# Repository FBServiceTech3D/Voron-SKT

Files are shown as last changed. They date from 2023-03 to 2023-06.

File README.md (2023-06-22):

# Voron SKT Toolhead
Mod for Voron with umbilical 
<br/>
<br/>
SKT stands for "Skinny Tool" :)<br/>
Some things are inspired by EVA 2, thanks guys.<br/>
This toolhead is designed to be as light as possible with a "TAP" like probe. It will not be compatible with all extruders and all hotends or even with all types of toolboards due to its design and specificity.<br/>
STK toolhead allow the installation of SHT42/EBB42 toolboards only.><br/>
If you want to run fast, just try it.<br/><br/>
<B>Whit this mod you will able to use all the build plate on X axis, but you will lose about 8mm on Y axis</B><br/>
 
<br/>

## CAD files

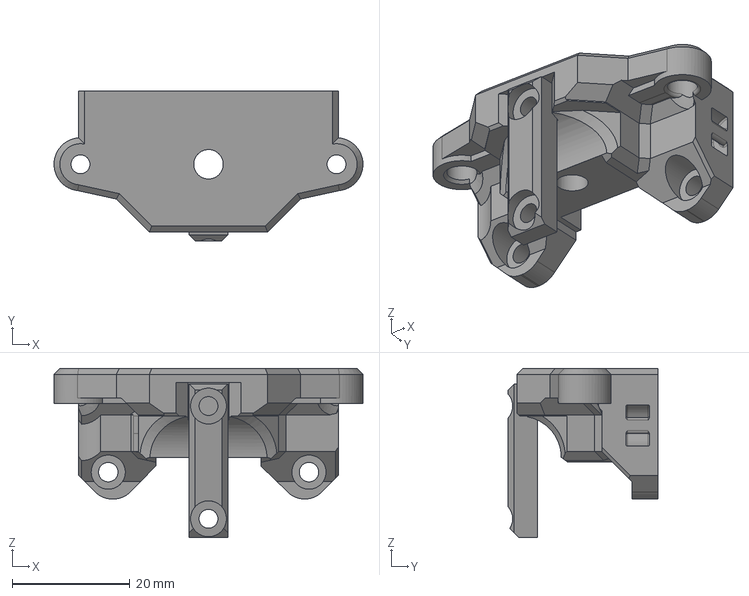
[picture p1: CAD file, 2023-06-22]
Stuff/CAD/Sherpa Mini - Stiffer v2.step
52.5 x 25.4 x 28.8 mm

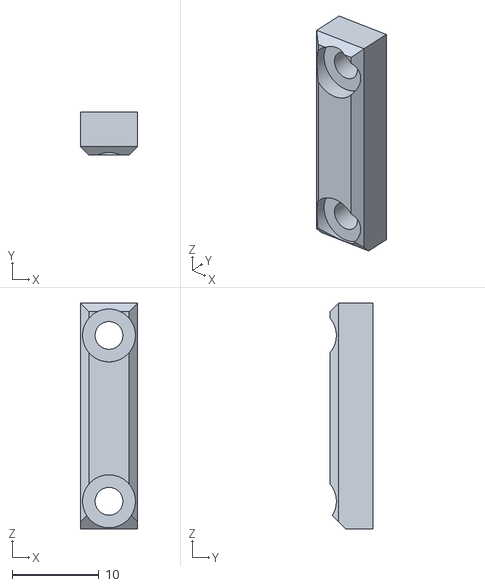
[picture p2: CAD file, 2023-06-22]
Stuff/STL/1.3 - Tap/Extruders/Sherpa micro stiffer/Barra irrigidimento.stl
6.60 x 5.00 x 26.1

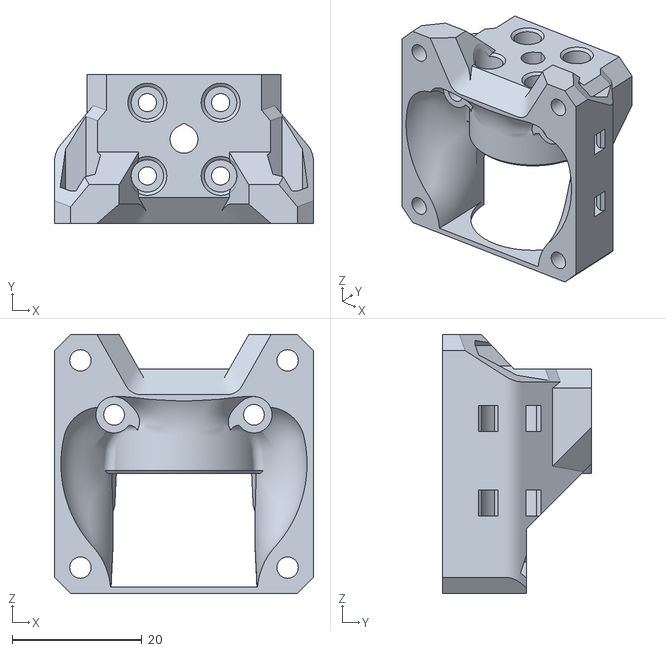
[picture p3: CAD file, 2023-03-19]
Stuff/STL/1.3 - Tap/Hotends/Masp Drg HF/Mount for MASP DRG HF.stl
40.0 x 23.0 x 40.0

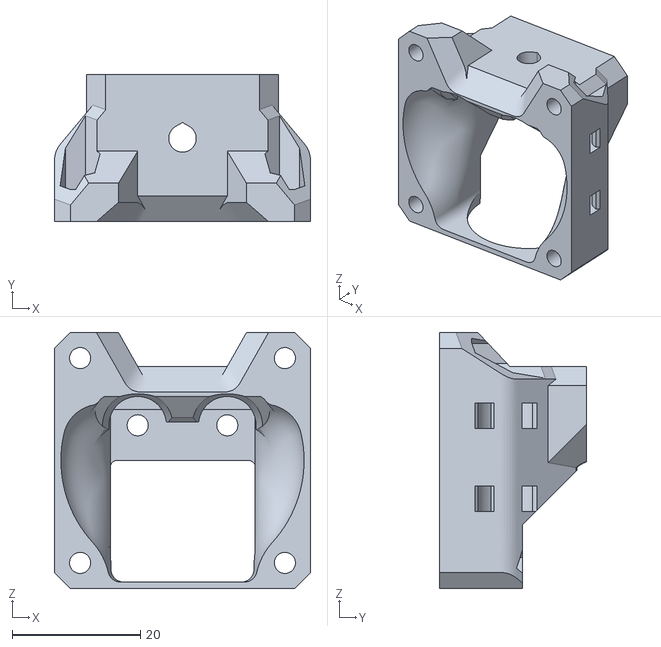
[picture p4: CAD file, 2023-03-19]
Stuff/STL/1.3 - Tap/Hotends/Masp Mk8 HF/Mount for MASP MK8 HF.stl
40.0 x 23.0 x 40.0

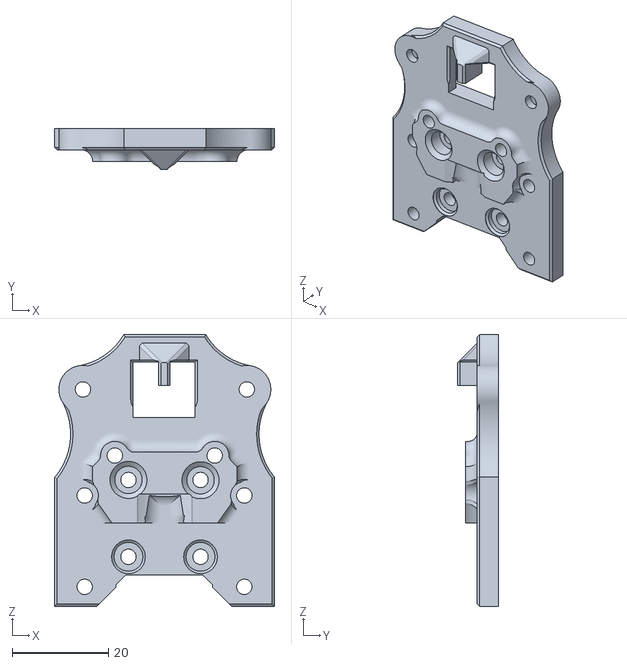
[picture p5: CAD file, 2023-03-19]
Stuff/STL/1.3 - Tap/Hotends/Phaetus Dragon HF/Front_Body_tap.stl
45.8 x 8.49 x 56.6

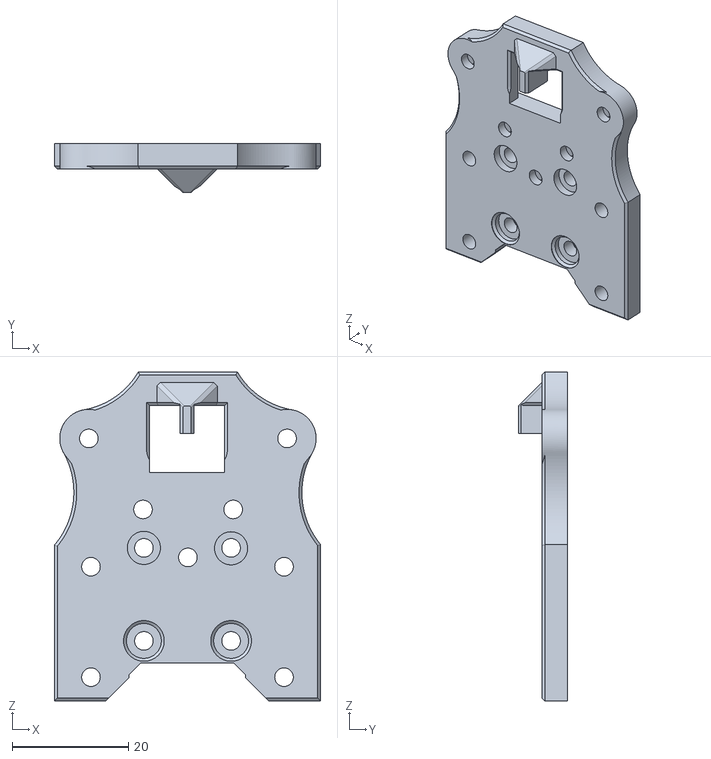
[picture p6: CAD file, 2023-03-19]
Stuff/STL/1.3 - Tap/Hotends/Phaetus Taichi/Front_Body_Tap.stl
45.8 x 8.49 x 56.6

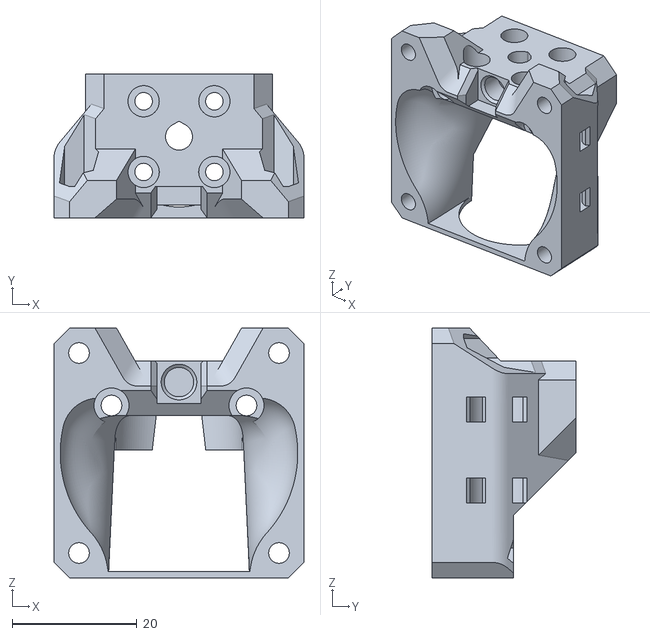
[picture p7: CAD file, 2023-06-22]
Stuff/STL/1.3 - Tap/Hotends/Rapido HF/Mount for Rapido HF - stiffer.stl
40.0 x 23.0 x 40.0

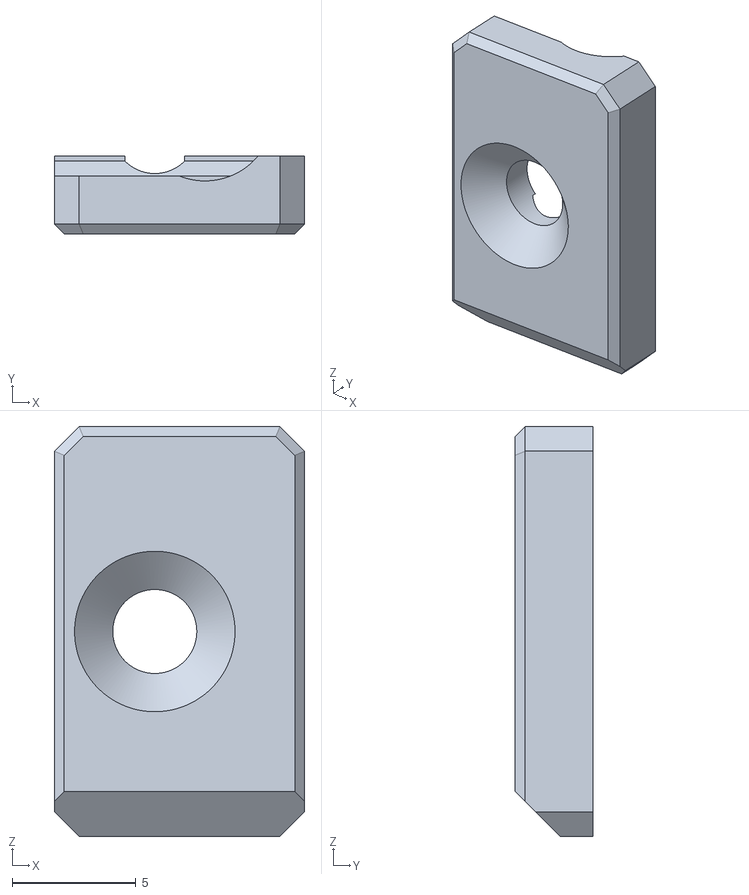
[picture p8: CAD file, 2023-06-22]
Stuff/STL/1.3 - Tap/Mgn12 Version/Carriage/6mm belt cover Left.stl
10.1 x 3.14 x 16.6

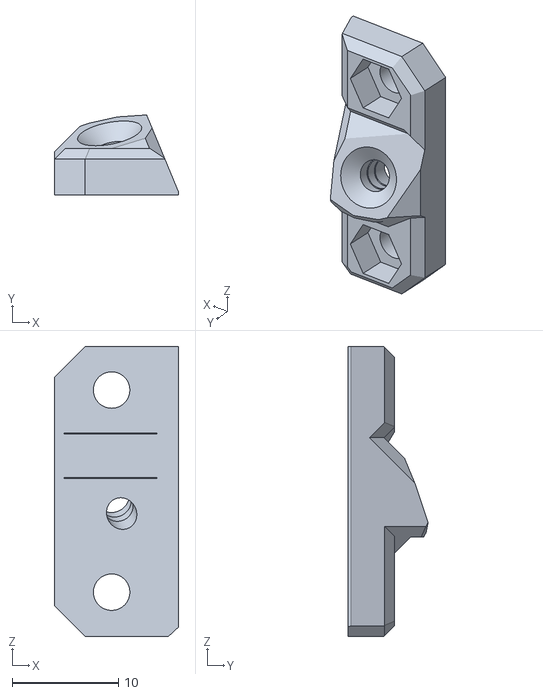
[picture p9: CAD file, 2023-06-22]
Stuff/STL/1.3 - Tap/Mgn12 Version/Tap System/Left Stopper.stl
11.7 x 7.54 x 27.3

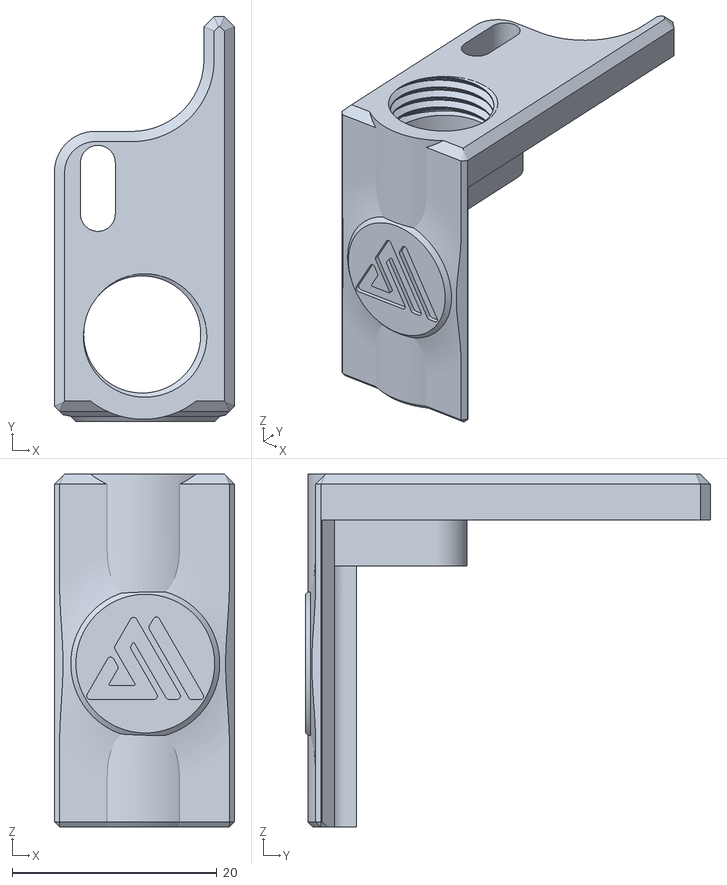
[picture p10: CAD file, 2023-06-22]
Stuff/STL/1.3 - Tap/Specific fo 2.4/[A] Stepper A - cable cover pg7.stl
17.6 x 39.6 x 34.5

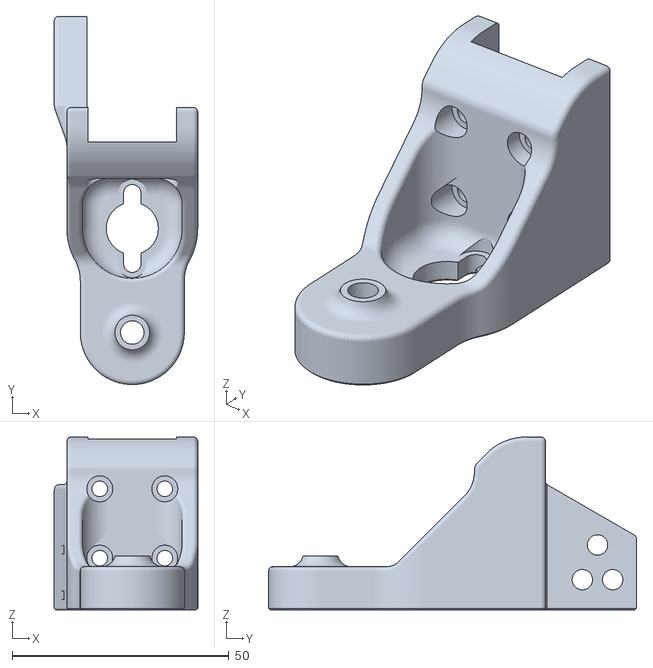
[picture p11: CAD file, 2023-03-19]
Stuff/STL/1.3 - Tap/Specific for Trident/z_carriage_rear_3hole.stl
33.1 x 84.9 x 39.9

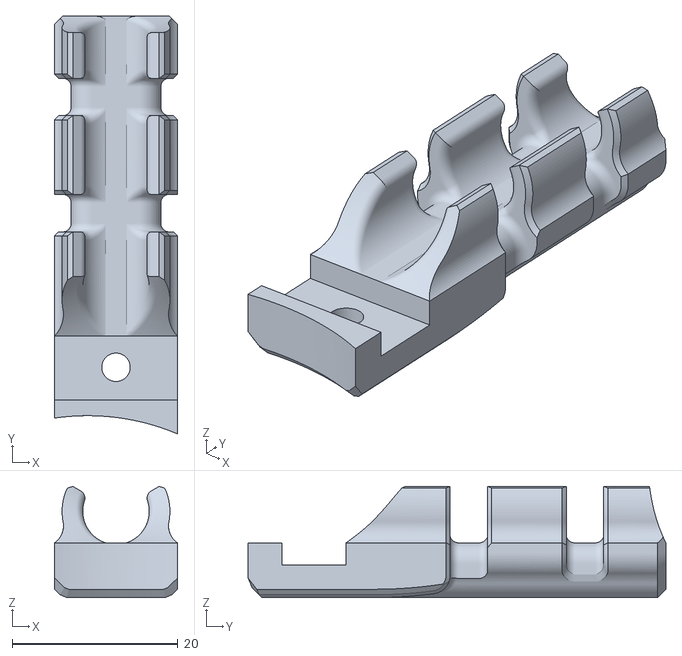
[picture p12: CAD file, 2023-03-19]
Stuff/STL/1.3 - Tap/Umbilical support 8mm.stl
14.8 x 50.4 x 13.4

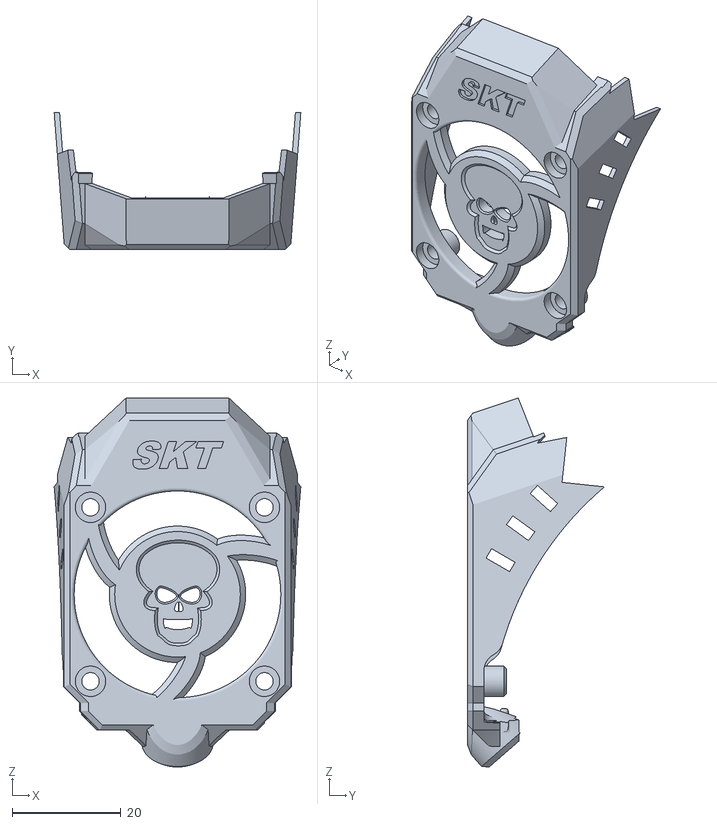
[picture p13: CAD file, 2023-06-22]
Stuff/STL/FacePlates/Skull No Eyes - Neopixel.stl
45.4 x 25.2 x 67.9

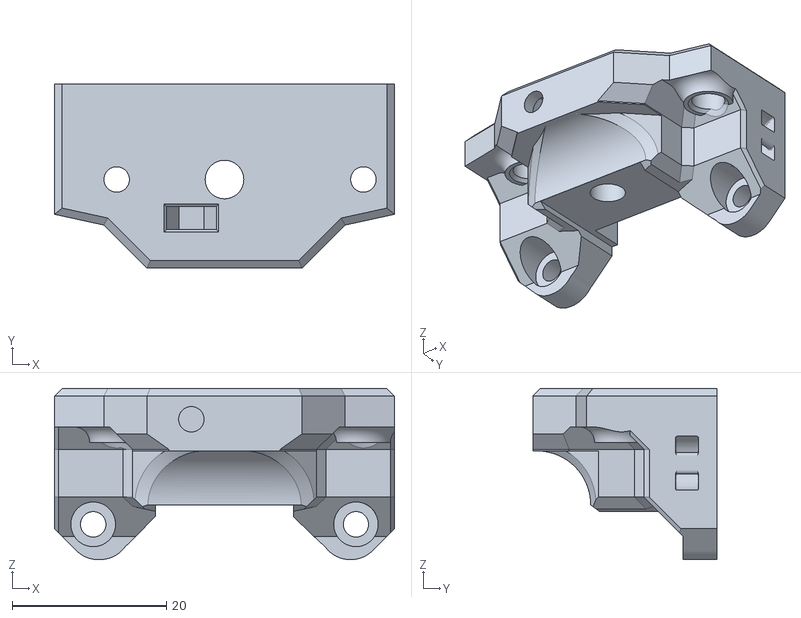
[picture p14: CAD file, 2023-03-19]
Stuff/STL/1.3 - Tap/Extruders/Mount for Sherpa Micro.stl
44.1 x 23.9 x 22.2

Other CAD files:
Stuff/STL/1.3 - Tap/Hotends/Masp Drg HF/Front_Body_tap.stl
Stuff/STL/1.3 - Tap/Hotends/Masp Mk8 HF/Front_Body_Tap.stl
Stuff/STL/1.3 - Tap/Hotends/Phaetus Dragon HF/Mount for Dragon HF.stl
Stuff/CAD/Sherpa Micro - No Front Screw - Stiffer v1.step
Stuff/STL/1.3 - Tap/Extruders/Mount For Libra Mini.stl
Stuff/STL/1.3 - Tap/Extruders/Mount for Lgx Lite.stl
Stuff/STL/1.3 - Tap/Extruders/Mount for Orbiter 1.5.stl
Stuff/STL/1.3 - Tap/Extruders/Mount for Sherpa Micro - No Front Screw.stl
Stuff/STL/1.3 - Tap/Extruders/Mount for Sherpa Mini.stl
Stuff/STL/1.3 - Tap/Extruders/Mount for Vz-Hextrudort Motor high.stl
Stuff/STL/1.3 - Tap/Extruders/Sherpa micro stiffer/Mount for Sherpa Micro - No Front Screw.stl
Stuff/STL/1.3 - Tap/Extruders/Sherpa mini stiffer/Mount for Sherpa Mini - No Front Screw - stiffer.stl
Stuff/STL/1.3 - Tap/Hotends/Phaetus Taichi/Mount for Taichi.stl
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

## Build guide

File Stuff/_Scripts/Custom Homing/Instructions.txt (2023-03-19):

1) Include the "SKT-Homing.cfg" file in the printer.cfg or copy its contents into your macro file if you have one.

2) In the printer.cfg file set [safe_z_home] as follows (or add it if not present):

[safe_z_home]
home_xy_position:117.5,117.5  #set your right coordinates of the center
speed:150				#set your preferred homing speed
z_hop:0				#Keep this value = 0

3) In the printer.cfg file add as follows:

[force_move]
enable_force_move: True		#Keep this value = True

4) In your macro of "END_PRINT" (it could be called something else) verify that there is "G28 X Y", if so add after the head has moved away from the bed

5) In your "PAUSE" macro set the parking coordinates as follows:

  {% set x_park = printer.toolhead.axis_maximum.x|float - 80.0  %}
  {% set y_park = printer.toolhead.axis_maximum.y|float - 40.0 %}

-end-

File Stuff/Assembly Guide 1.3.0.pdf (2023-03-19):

# SKT

# TAP Edition

# ASSEMBLY GUIDE

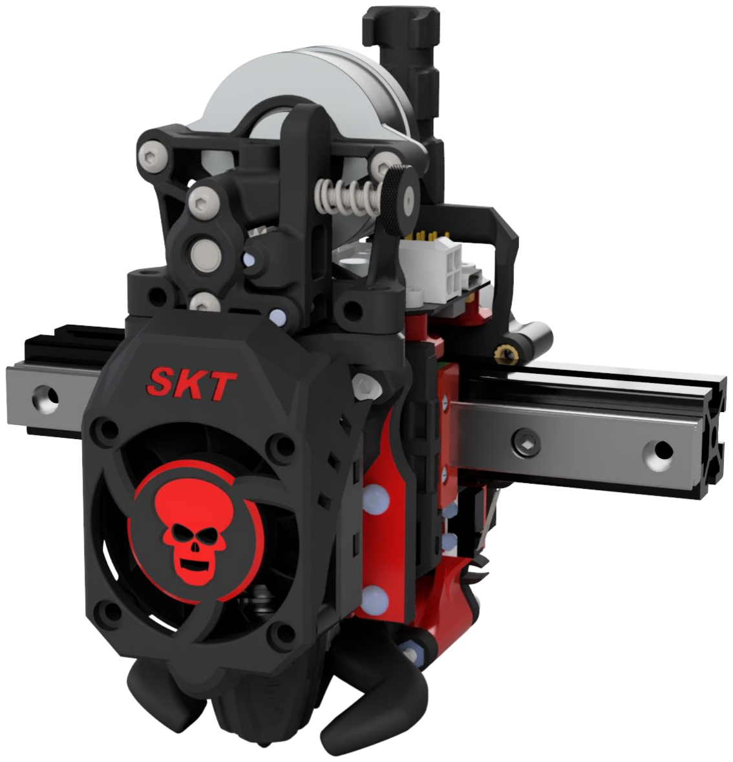
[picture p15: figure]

## Index

## Hardware reference

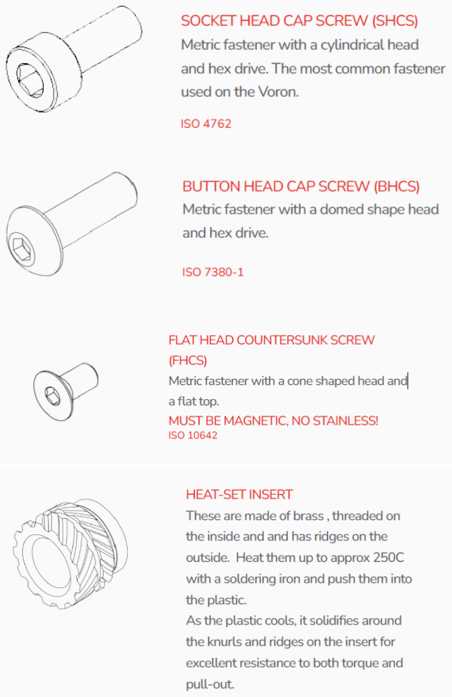
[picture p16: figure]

Threaded inserts have to be M3x5x4 type

## Step 1: Front carriage

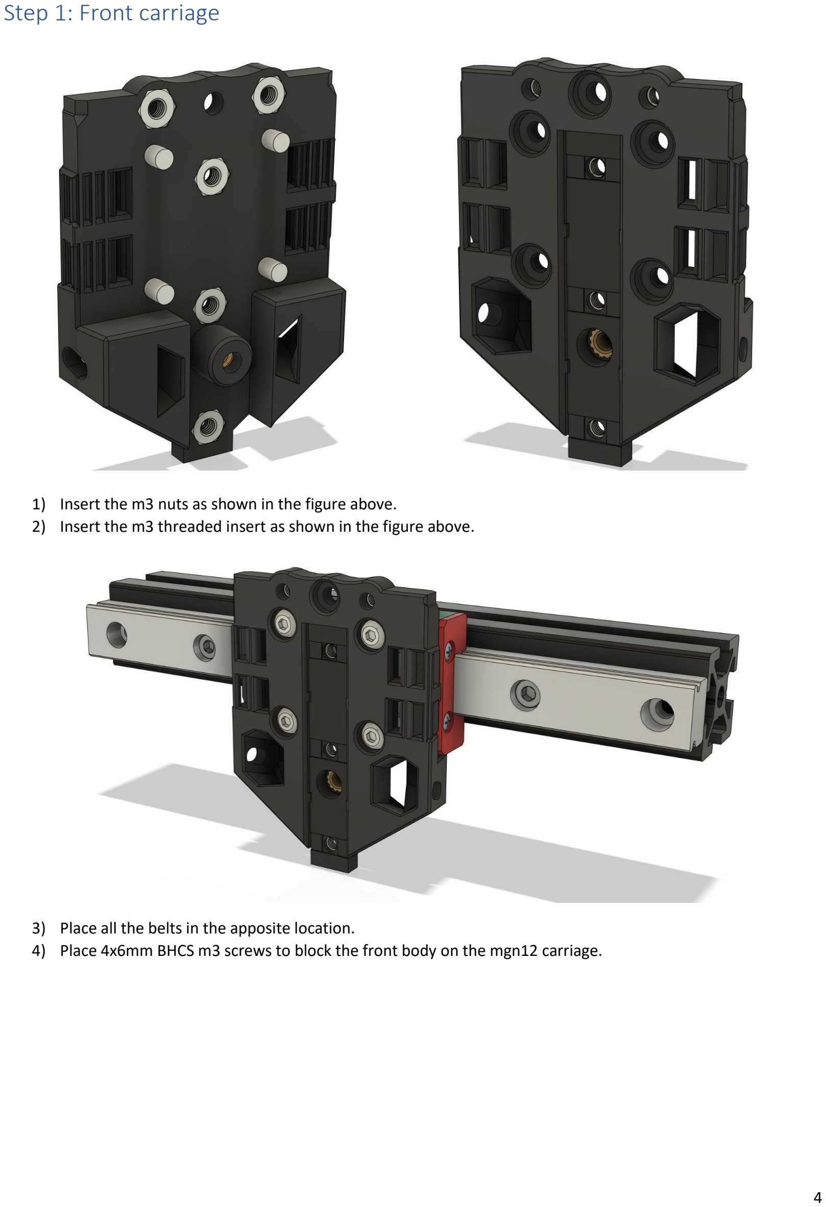
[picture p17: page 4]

1) Insert the m3 nuts as shown in the figure above.
2) Insert the m3 threaded insert as shown in the figure above.
3) Place all the belts in the apposite location.
4) Place 4x6mm BHCS m3 screws to block the front body on the mgn12 carriage.

## Step 2: Rear carriage

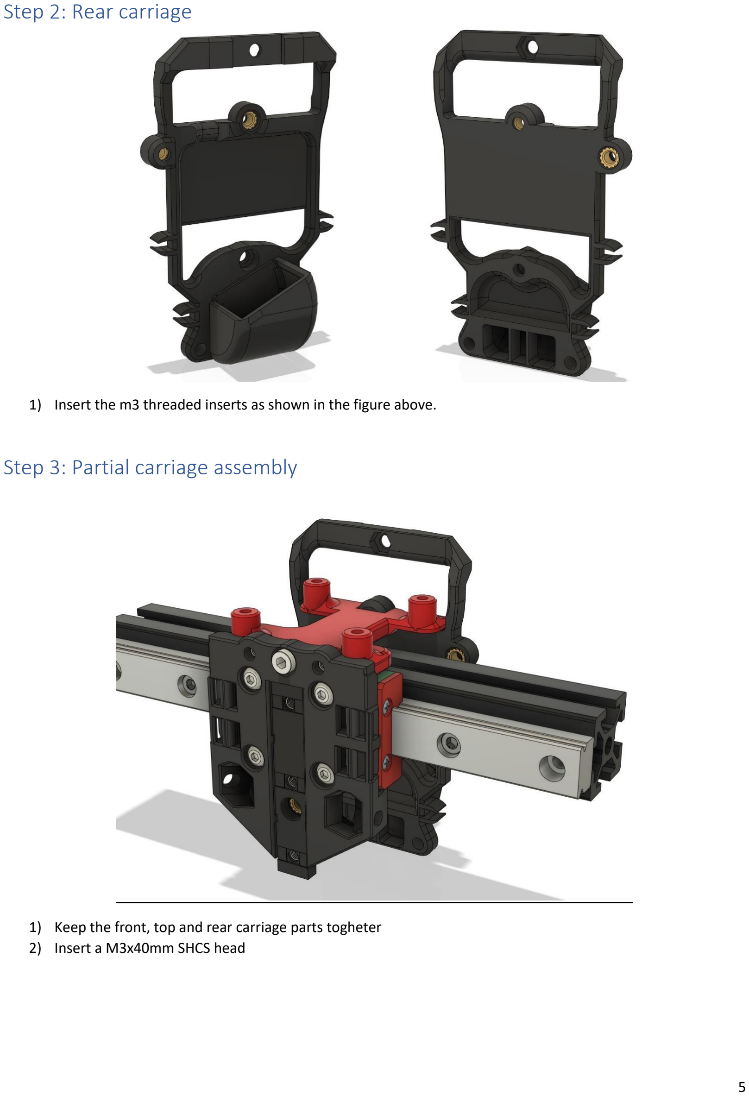
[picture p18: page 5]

1) Insert the m3 threaded inserts as shown in the figure above.

## Step 3: Partial carriage assembly

1) Keep the front, top and rear carriage parts togheter
2) Insert a M3x40mm SHCS head

## Step 4: Lower carriage assembly

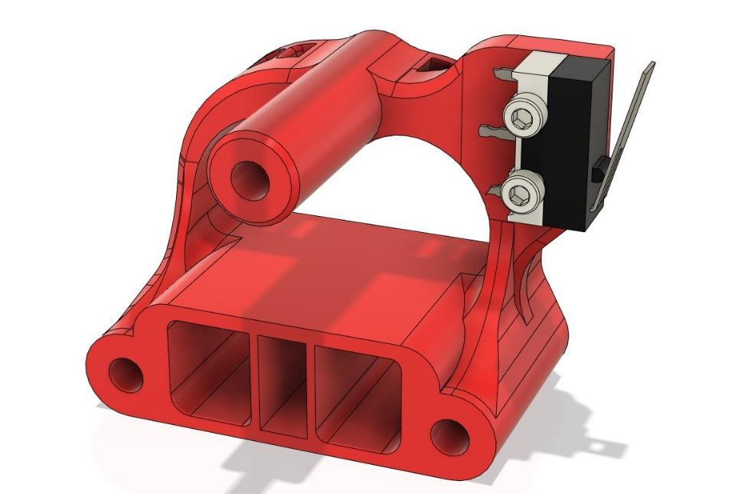
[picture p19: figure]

1) Insert 2 self-tapping screws M2x8mm (10mm as well) to lock the switch in right position

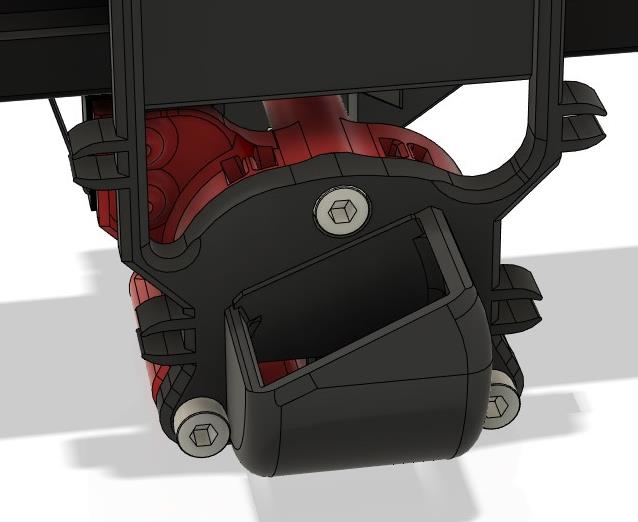
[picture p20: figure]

2) Insert 3 M3x35mm SHCS head as shown in the figure above. The center screw must be screwed into the front carriage insert.

## Step 5: Fanduct

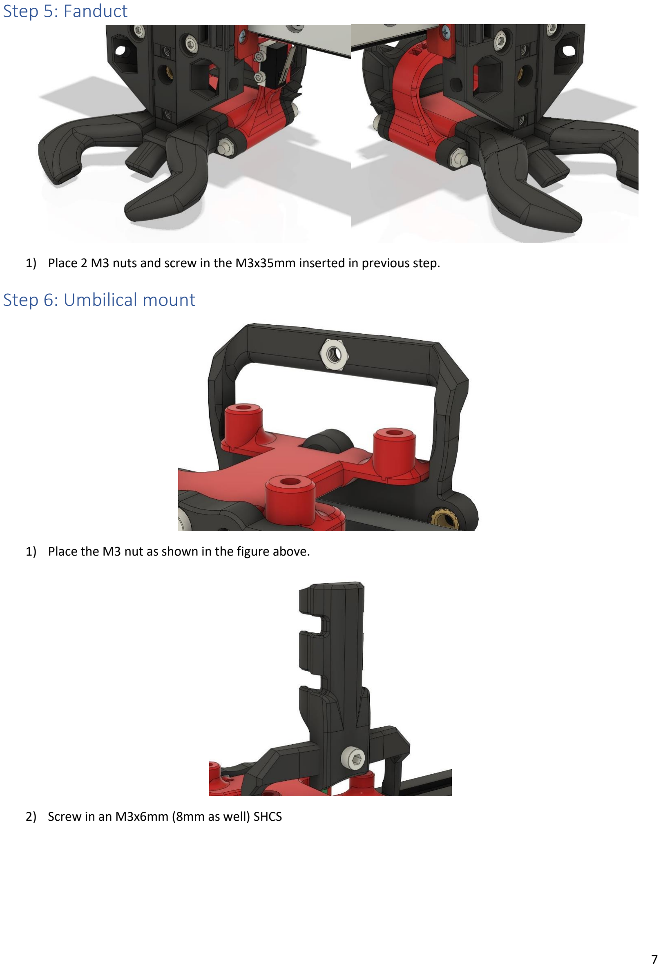
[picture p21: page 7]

1) Place 2 M3 nuts and screw in the M3x35mm inserted in previous step.

## Step 6: Umbilical mount

1) Place the M3 nut as shown in the figure above.
2) Screw in an M3x6mm (8mm as well) SHCS

## Step 7: Rear TAP system – initial assembly

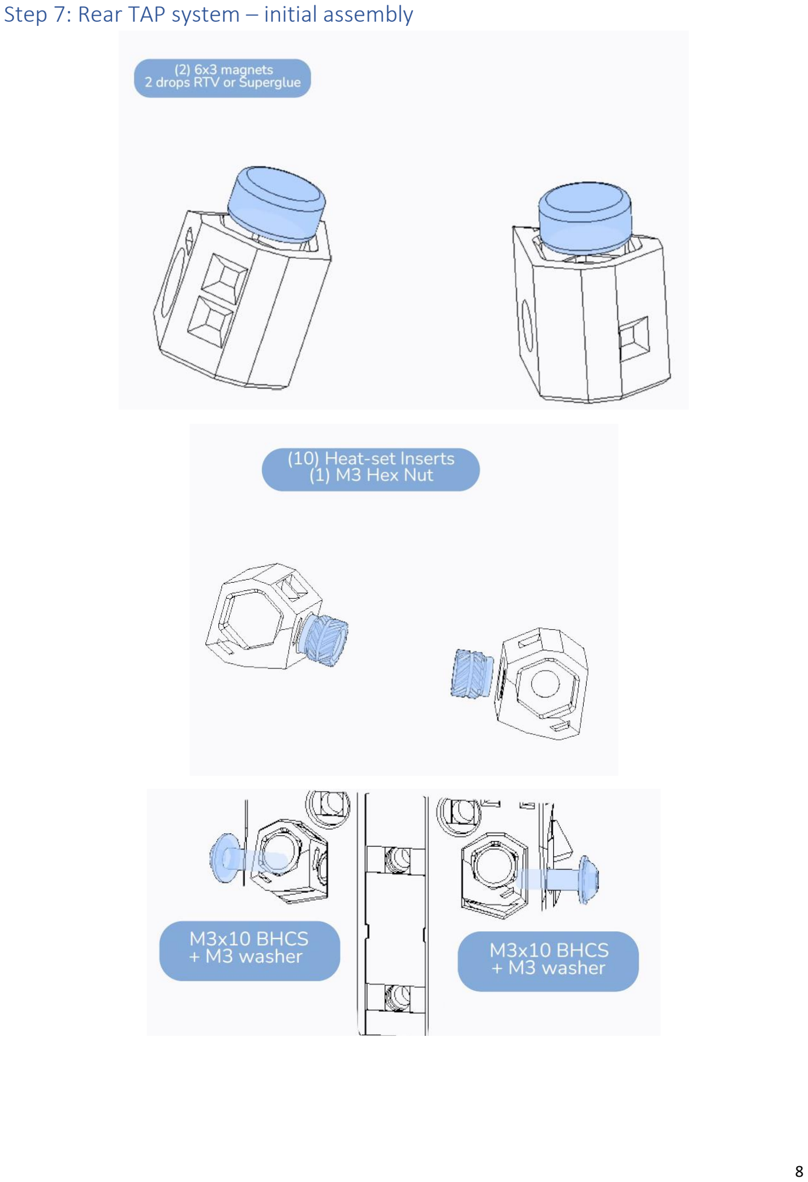
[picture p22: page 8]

## Step 8: Rear TAP system – MGN9 rail installation

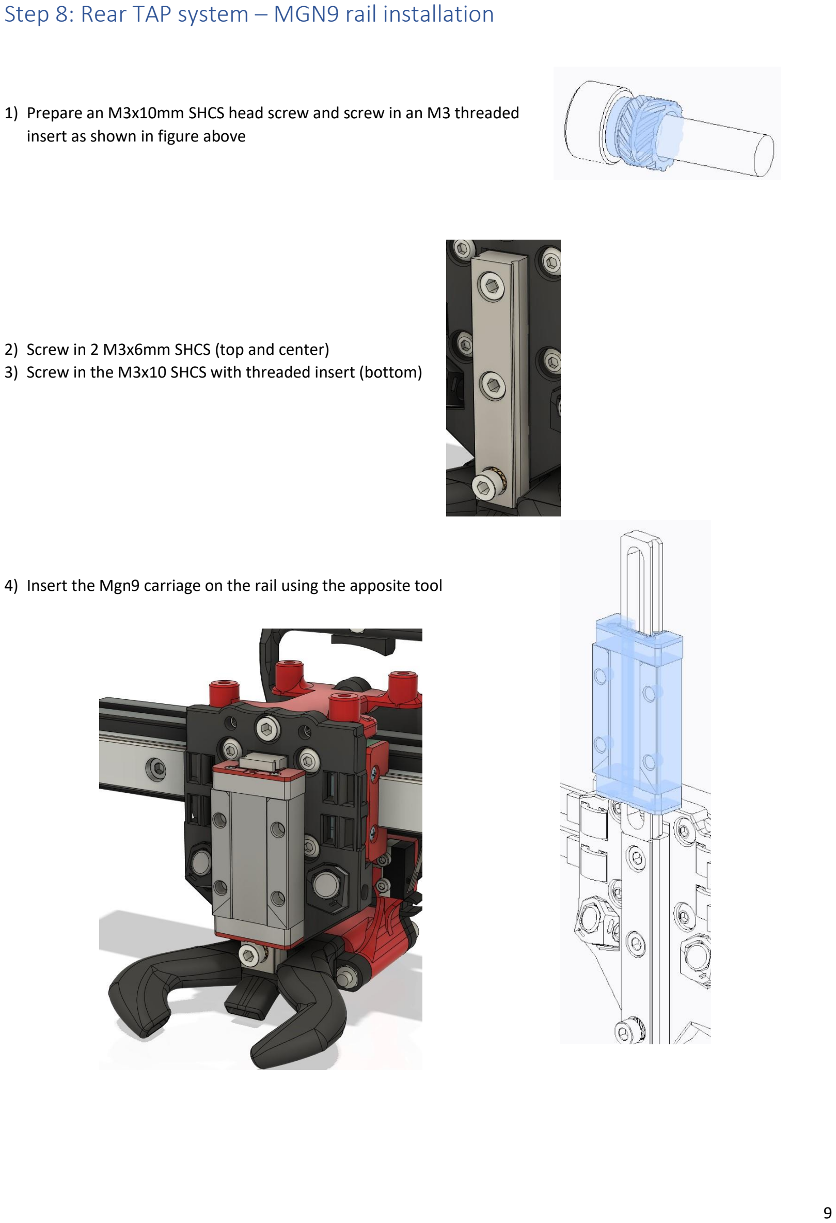
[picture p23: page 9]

1) Prepare an M3x10mm SHCS head screw and screw in an M3 threaded insert as shown in figure above
2) Screw in 2 M3x6mm SHCS (top and center)
3) Screw in the M3x10 SHCS with threaded insert (bottom)
4) Insert the Mgn9 carriage on the rail using the apposite tool

## Step 9: Rear TAP system – Probe installation

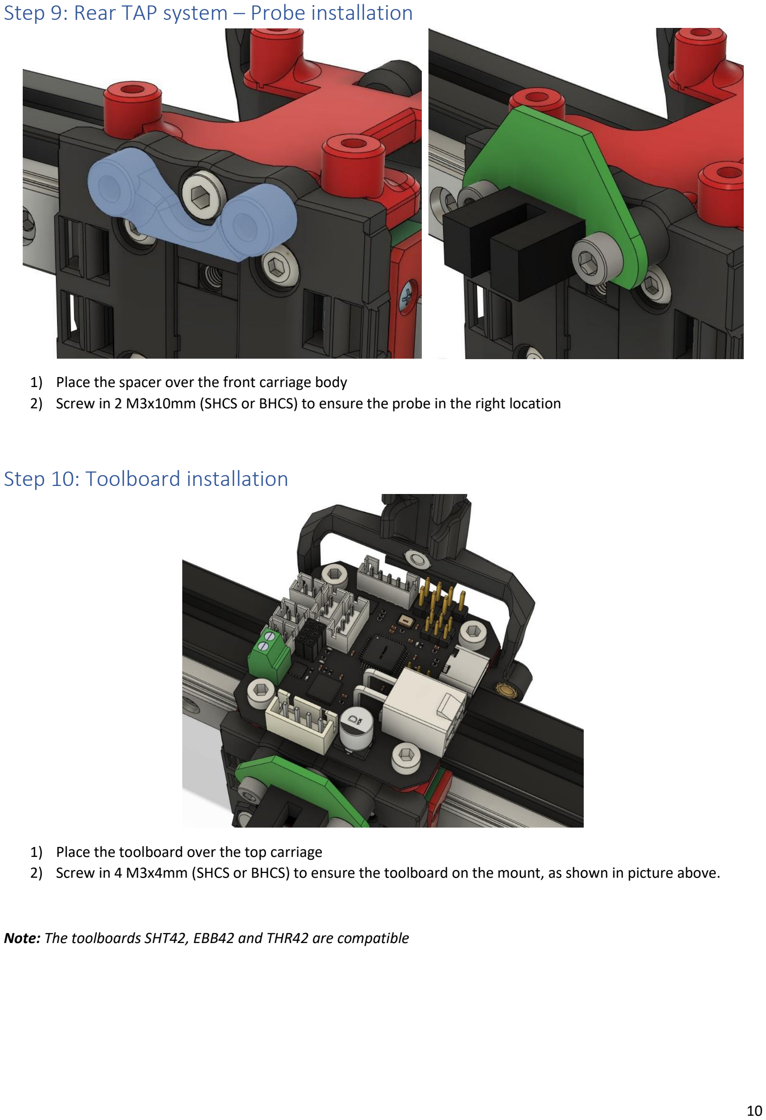
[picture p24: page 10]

1) Place the spacer over the front carriage body
2) Screw in 2 M3x10mm (SHCS or BHCS) to ensure the probe in the right location

## Step 10: Toolboard installation

1) Place the toolboard over the top carriage
2) Screw in 4 M3x4mm (SHCS or BHCS) to ensure the toolboard on the mount, as shown in picture above.

Note: The toolboards SHT42, EBB42 and THR42 are compatible

## Step 11: Front TAP system

1) Place 6 M3 nuts as shown in picture on the side

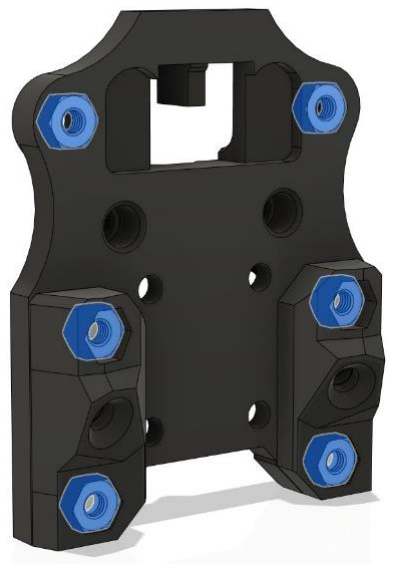
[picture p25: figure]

2) Screw in 4 M3x8mm BHCS as shown in picture on the side

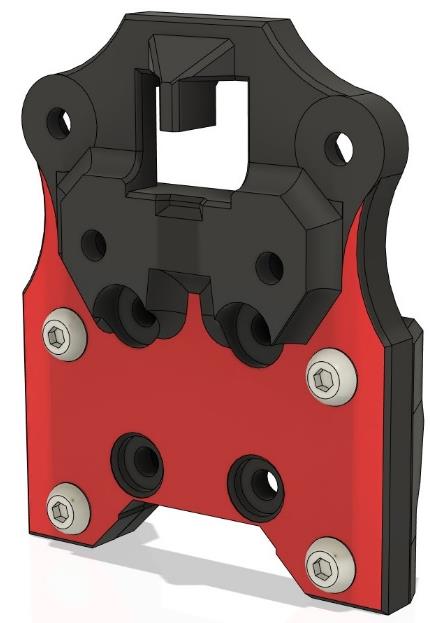
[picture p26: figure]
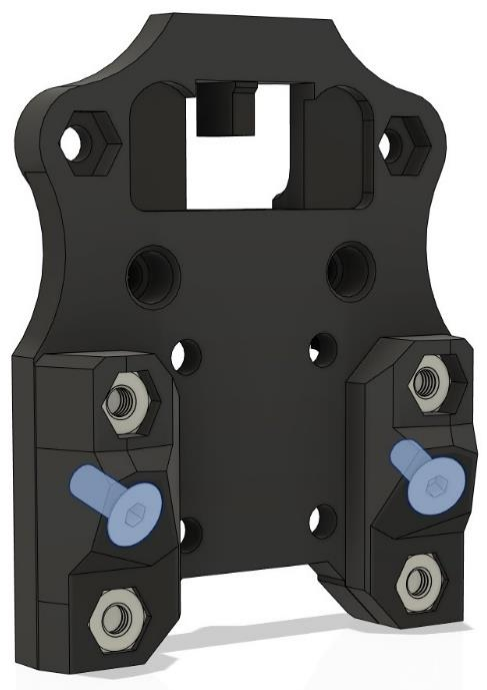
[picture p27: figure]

3) Screw in 2 M3x6mm FHCS as shown in picture on the side

The holes here are designed at an angle.
Go slow. Tighten the FHCS until they are flush, but do not over tighten.

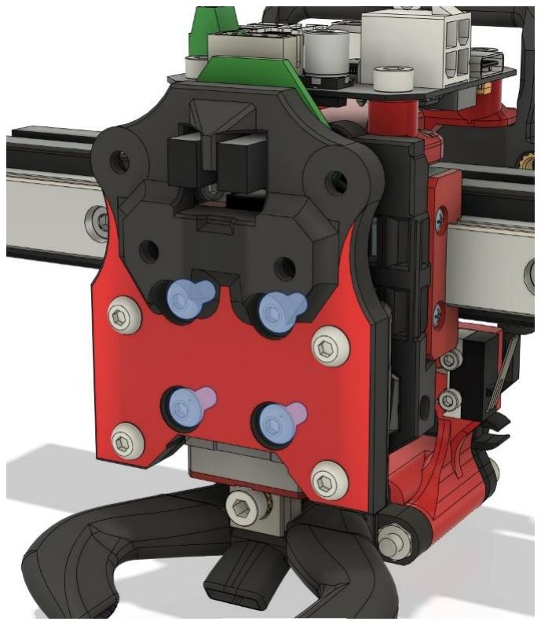
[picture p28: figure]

4) Screw in 4 M3x6mm BHCS as shown in picture on the side, to ensure the front tap system to the MGN9 carriage

## Step 12: Extruder adapter installation

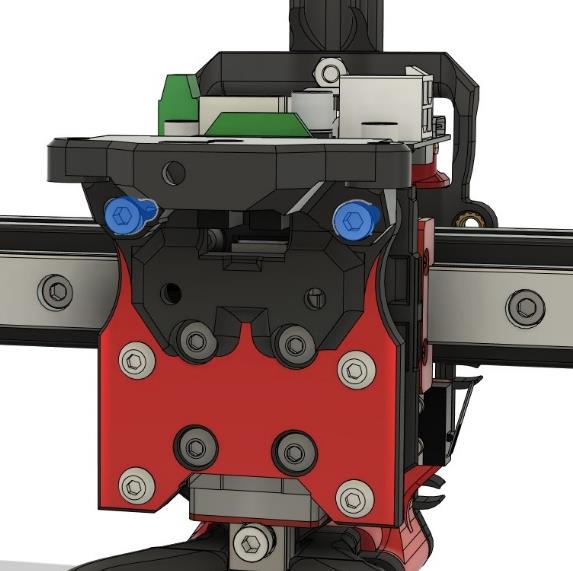
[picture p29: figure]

1) Place the adapter as show in side picture
2) Screw in 2 M3x8mm SHCS to ensure the adapter

## Step 12: Hotend installation

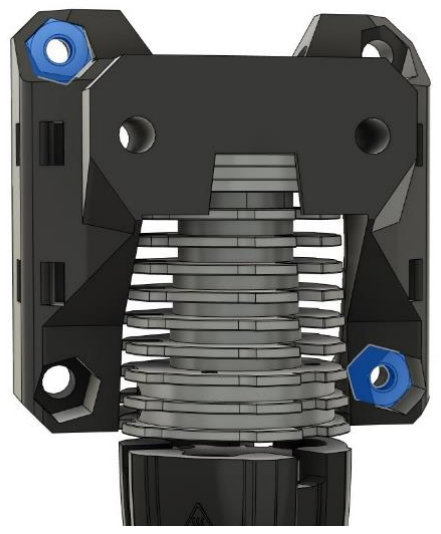
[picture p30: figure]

1) Insert 2 (4 if you want) M3 nuts as shown in side picture
2) Screw in 2 SHCS screws to ensure the hotend mount.

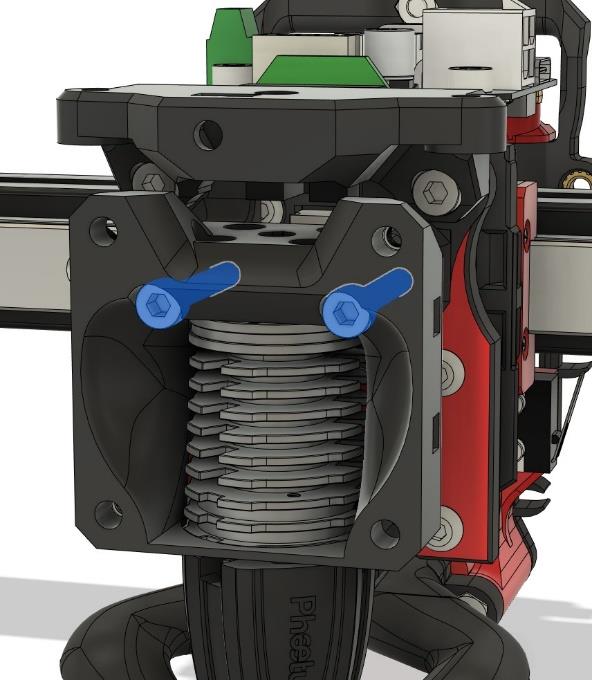
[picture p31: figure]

Note: The screws to be used in this step can change according to the different hotend types

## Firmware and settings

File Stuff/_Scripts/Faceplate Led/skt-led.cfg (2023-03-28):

[neopixel skt_leds]
pin: EBBCan:PD3
chain_count: 1
#   The number of Neopixel chips that are "daisy chained" to the
#   provided pin. The default is 1 (which indicates only a single
#   Neopixel is connected to the pin).
color_order: GRBW
#   Set the pixel order required by the LED hardware. Options are GRB,
#   RGB, GRBW, or RGBW. The default is GRB.
initial_RED: 1.0
initial_GREEN: 1.0
initial_BLUE: 1.0
initial_WHITE: 1.0
#   Sets the initial LED color of the Neopixel. Each value should be
#   between 0.0 and 1.0. The WHITE option is only available on RGBW
#   LEDs. The default for each color is 0.#

# Most configuration for the macros can be done by modifying the variables in the _skt_vars macro
# at the start of this file.

[gcode_macro _skt_vars]
# User settings for the StealthBurner status leds. You can change the status colors and led
# configurations for the logo and nozzle here.
variable_colors: {       
        'nozzle': { # Colors for nozzle states
            'heating': {'r': 0.8, 'g': 0.35, 'b': 0.0, 'w':0.0},
            'off': {'r': 0.0, 'g': 0.0, 'b': 0.0, 'w': 0.0},
            'on': {'r': 0.8, 'g': 0.8, 'b': 0.8, 'w':1.0},
            'standby': {'r': 0.6, 'g': 0.0, 'b': 0.0, 'w':0.0},
            'busy': {'r': 0.4, 'g': 0.0, 'b': 0.0, 'w': 0.0},
            'cleaning': {'r': 0.0, 'g': 0.02, 'b': 0.5, 'w': 0.0},
            'calibrating_z': {'r': 0.8, 'g': 0., 'b': 0.35, 'w': 0.0},         
            'homing': {'r': 0.0, 'g': 0.6, 'b': 0.2, 'w': 0.0},
            'leveling': {'r': 0.5, 'g': 0.1, 'b': 0.4, 'w': 0.0},
            'meshing': {'r': 0.2, 'g': 1.0, 'b': 0.0, 'w': 0.0},          
            'printing': {'r': 1.0, 'g': 0.0, 'b': 0.0, 'w': 0.0},
        },
        'thermal': {
            'hot': {'r': 1.0, 'g': 0.0, 'b': 0.0, 'w': 0.0},
            'cold': {'r': 0.3, 'g': 0.0, 'b': 0.3, 'w': 0.0}
        }
 }
variable_nozzle_led_name: "skt_leds"
# The name of the addressable LED chain that contains the nozzle LED(s). This will
# typically be the same LED chain as the logo.
variable_nozzle_idx: "1"
# A comma-separated list of indexes of LEDs in the nozzle
gcode:
    # This section is required.  Do Not Delete.

[gcode_macro _set_skt_leds]
gcode:
    {% set red = params.RED|default(0)|float %}
    {% set green = params.GREEN|default(0)|float %}
    {% set blue = params.BLUE|default(0)|float %}
    {% set white = params.WHITE|default(0)|float %}
    {% set led = params.LED|string %}
    {% set idx = (params.IDX|string).split(',') %}
    {% set transmit_last = params.TRANSMIT|default(1) %}

    {% for led_index in idx %}
        {% set transmit=transmit_last if loop.last else 0 %}
        set_led led={led} red={red} green={green} blue={blue} white={white} index={led_index} transmit={transmit}
    {% endfor %}

[gcode_macro _set_skt_leds_by_name]
gcode:
    {% set leds_name = params.LEDS %}
    {% set color_name = params.COLOR %}
    {% set color = printer["gcode_macro _skt_vars"].colors[leds_name][color_name] %}
    {% set led = printer["gcode_macro _skt_vars"][leds_name + "_led_name"] %}
    {% set idx = printer["gcode_macro _skt_vars"][leds_name + "_idx"] %}
    {% set transmit = params.TRANSMIT|default(1) %}

    _set_skt_leds led={led} red={color.r} green={color.g} blue={color.b} white={color.w} idx="{idx}" transmit={transmit}
 
[gcode_macro _set_nozzle_leds]
gcode:
    {% set red = params.RED|default(0)|float %}
    {% set green = params.GREEN|default(0)|float %}
    {% set blue = params.BLUE|default(0)|float %}
    {% set white = params.WHITE|default(0)|float %}
    {% set led = printer["gcode_macro _skt_vars"].nozzle_led_name %}
    {% set idx = printer["gcode_macro _skt_vars"].nozzle_idx %}
    {% set transmit=params.TRANSMIT|default(1) %}

    _set_skt_leds led={led} red={red} green={green} blue={blue} white={white} idx="{idx}" transmit={transmit}

 
[gcode_macro set_nozzle_leds_on]
gcode:
    {% set transmit=params.TRANSMIT|default(1) %}
    _set_skt_leds_by_name leds="nozzle" color="on" transmit={transmit}

[gcode_macro set_nozzle_leds_off]
gcode:
    {% set transmit=params.TRANSMIT|default(1) %}
    _set_skt_leds_by_name leds="nozzle" color="off" transmit={transmit}

[gcode_macro status_off]
gcode:
    set_nozzle_leds_off

[gcode_macro status_ready]
gcode:
    _set_skt_leds_by_name leds="nozzle" color="standby" transmit=1

[gcode_macro status_busy]
gcode:
    _set_skt_leds_by_name leds="nozzle" color="busy" transmit=1

[gcode_macro status_heating]
gcode:
    _set_skt_leds_by_name leds="nozzle" color="heating" transmit=1

[gcode_macro status_leveling]
gcode:
    _set_skt_leds_by_name leds="nozzle" color="leveling" transmit=1

[gcode_macro status_homing]
gcode:
    _set_skt_leds_by_name leds="nozzle" color="homing" transmit=1

[gcode_macro status_cleaning]
gcode:
    _set_skt_leds_by_name leds="nozzle" color="cleaning" transmit=1

[gcode_macro status_meshing]
gcode:
    _set_skt_leds_by_name leds="nozzle" color="meshing" transmit=1

[gcode_macro status_calibrating_z]
gcode:
    _set_skt_leds_by_name leds="nozzle" color="calibrating_z" transmit=1

[gcode_macro status_printing]
gcode:
    _set_skt_leds_by_name leds="nozzle" color="printing" transmit=1
